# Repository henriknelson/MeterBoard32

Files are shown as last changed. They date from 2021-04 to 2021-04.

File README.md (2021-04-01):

# MeterBoard32
KiCad hardware project to integrate Texas Instruments TSS721-ADR M-Bus transceiver with Espressifs ESP32-WROOM module on a single PCB.

3D View:
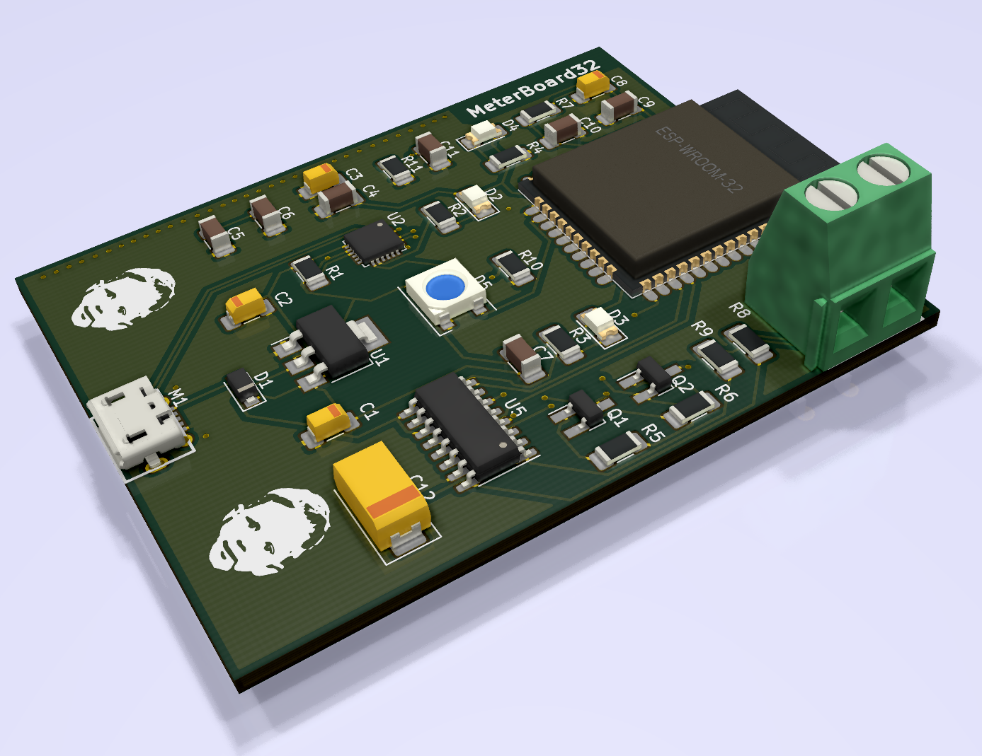
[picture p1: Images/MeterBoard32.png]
MeterBoard32 PCB 3D View


Schematic:
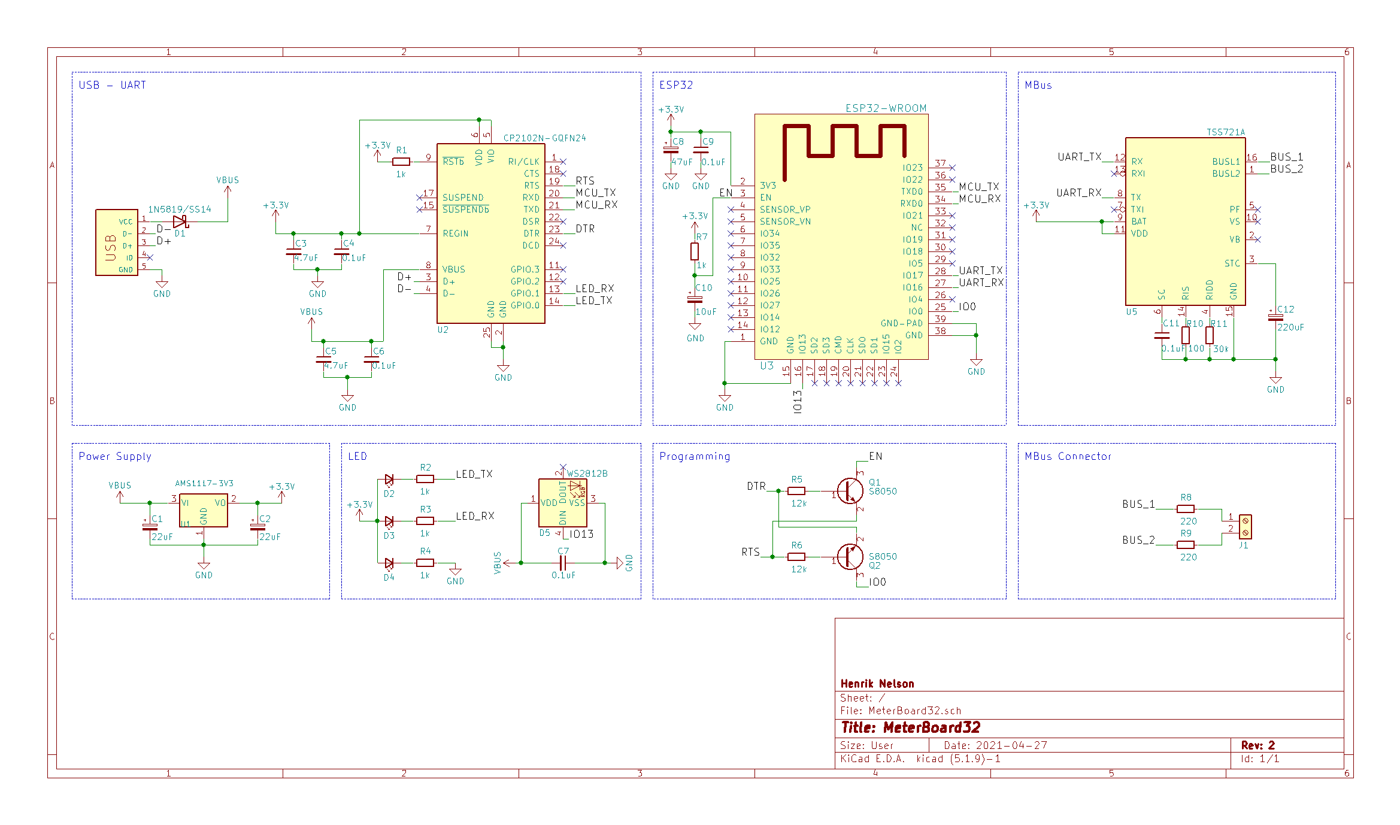
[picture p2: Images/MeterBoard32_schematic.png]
MeterBoard32 Schematic


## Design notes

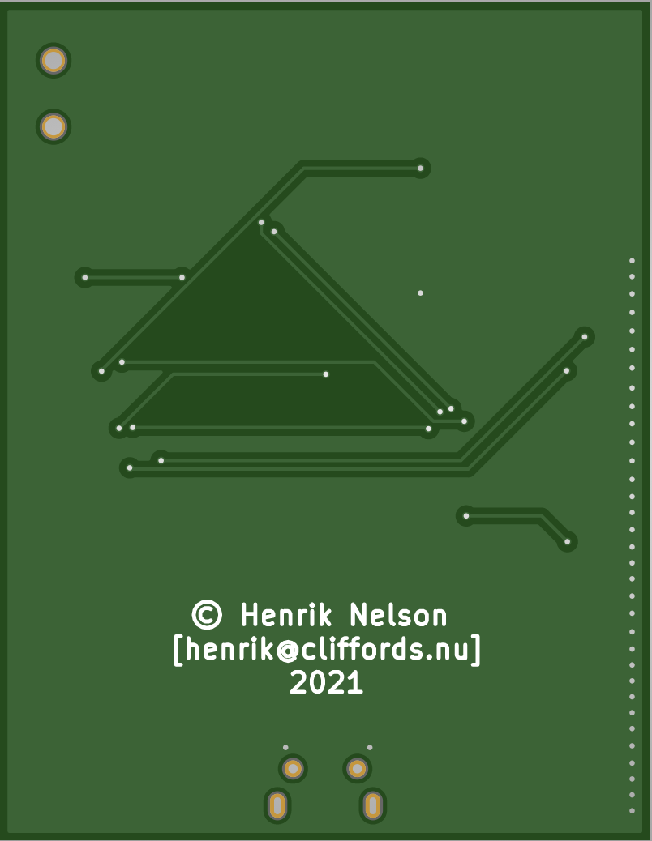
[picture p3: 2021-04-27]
Images/MeterBoard32_PCB_Back.png

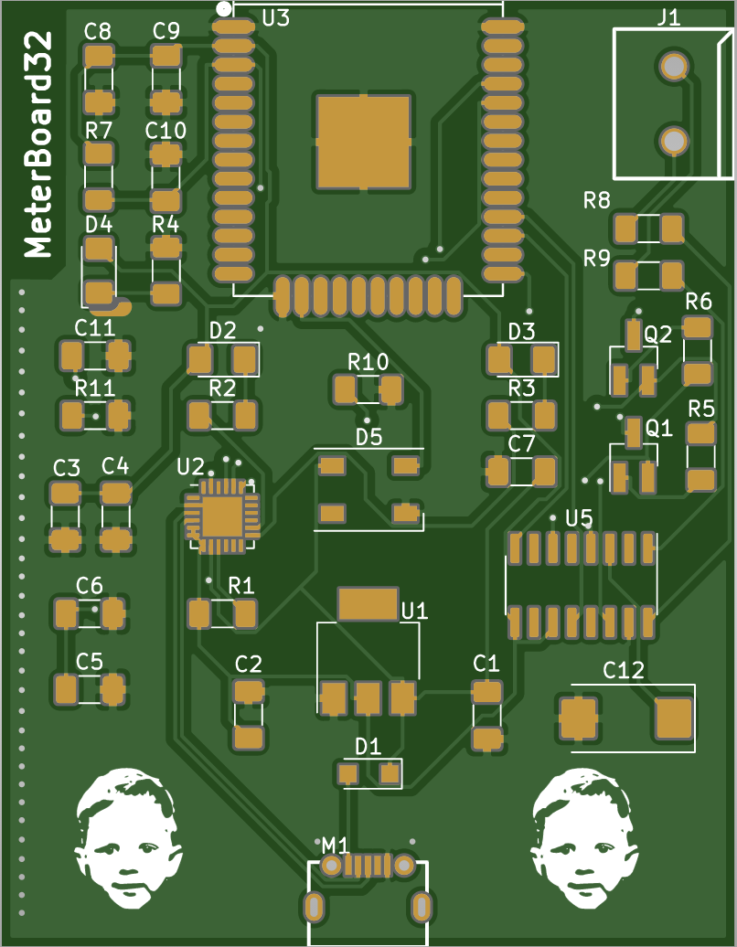
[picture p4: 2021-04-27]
Images/MeterBoard32_PCB_Front.png

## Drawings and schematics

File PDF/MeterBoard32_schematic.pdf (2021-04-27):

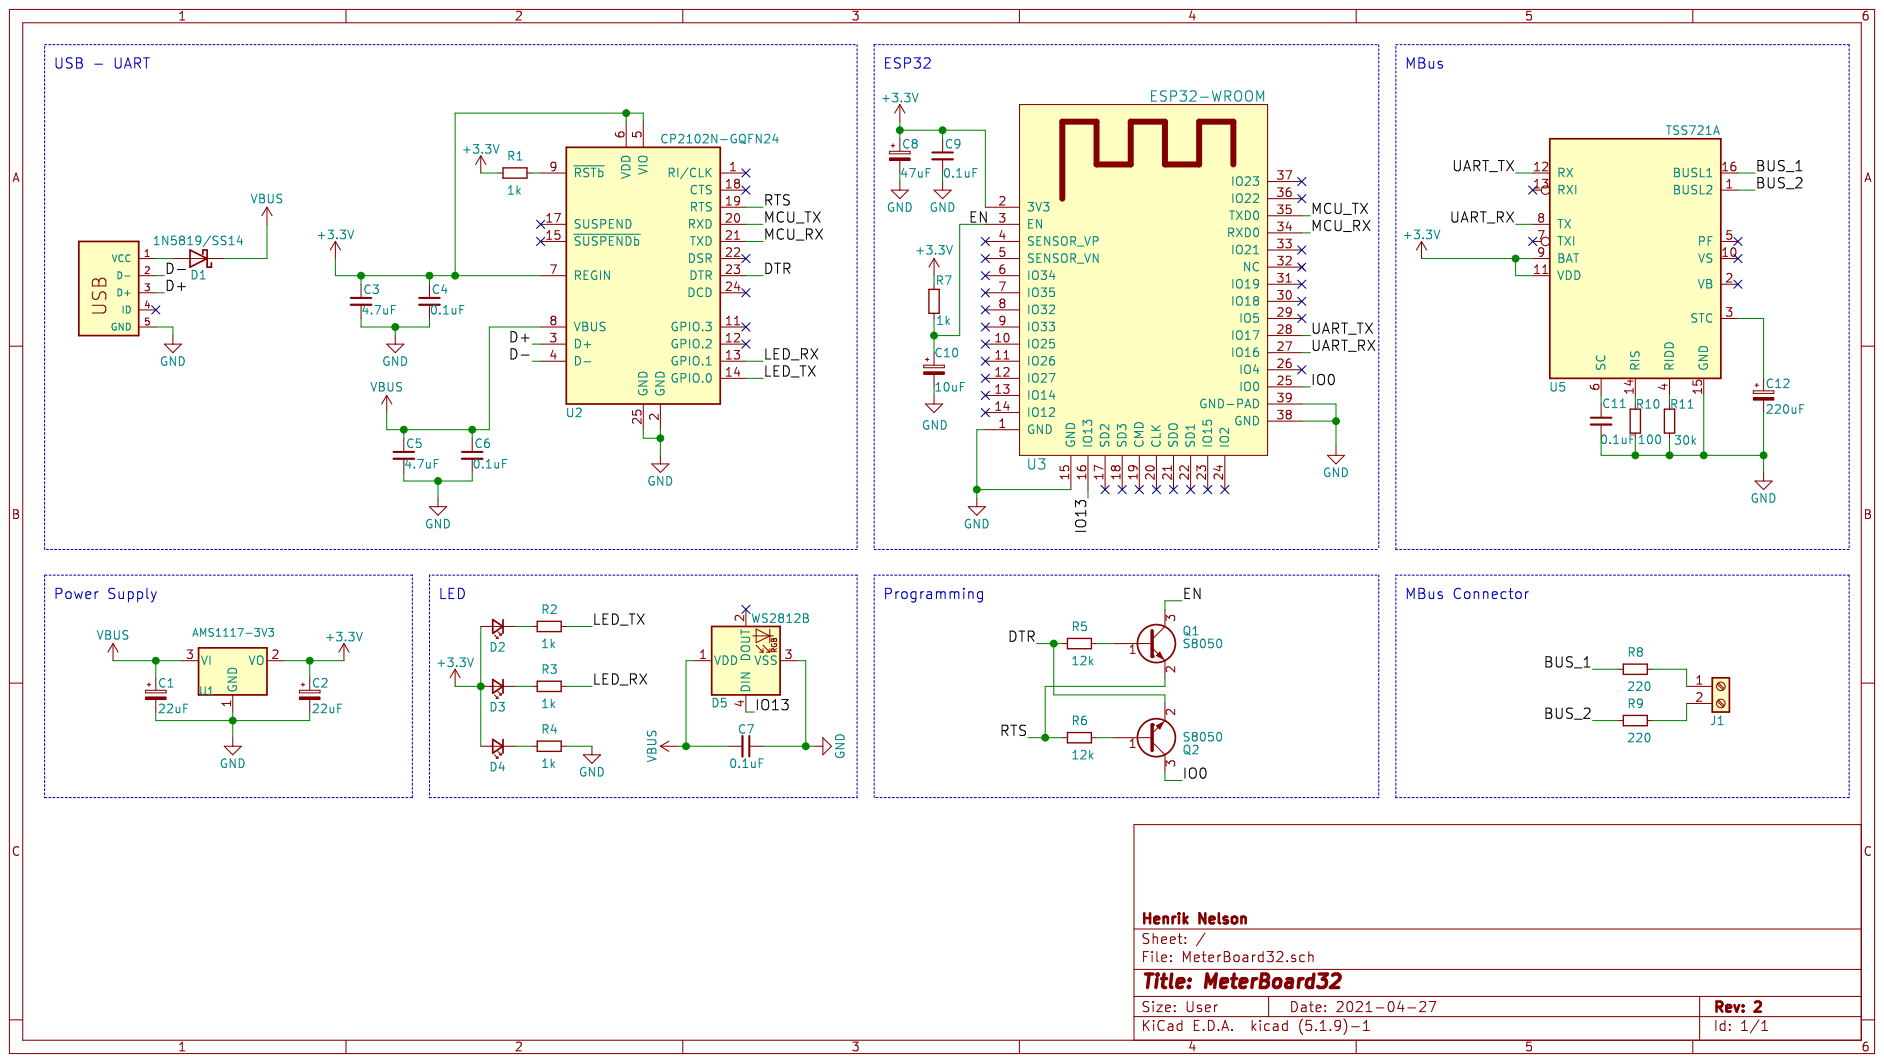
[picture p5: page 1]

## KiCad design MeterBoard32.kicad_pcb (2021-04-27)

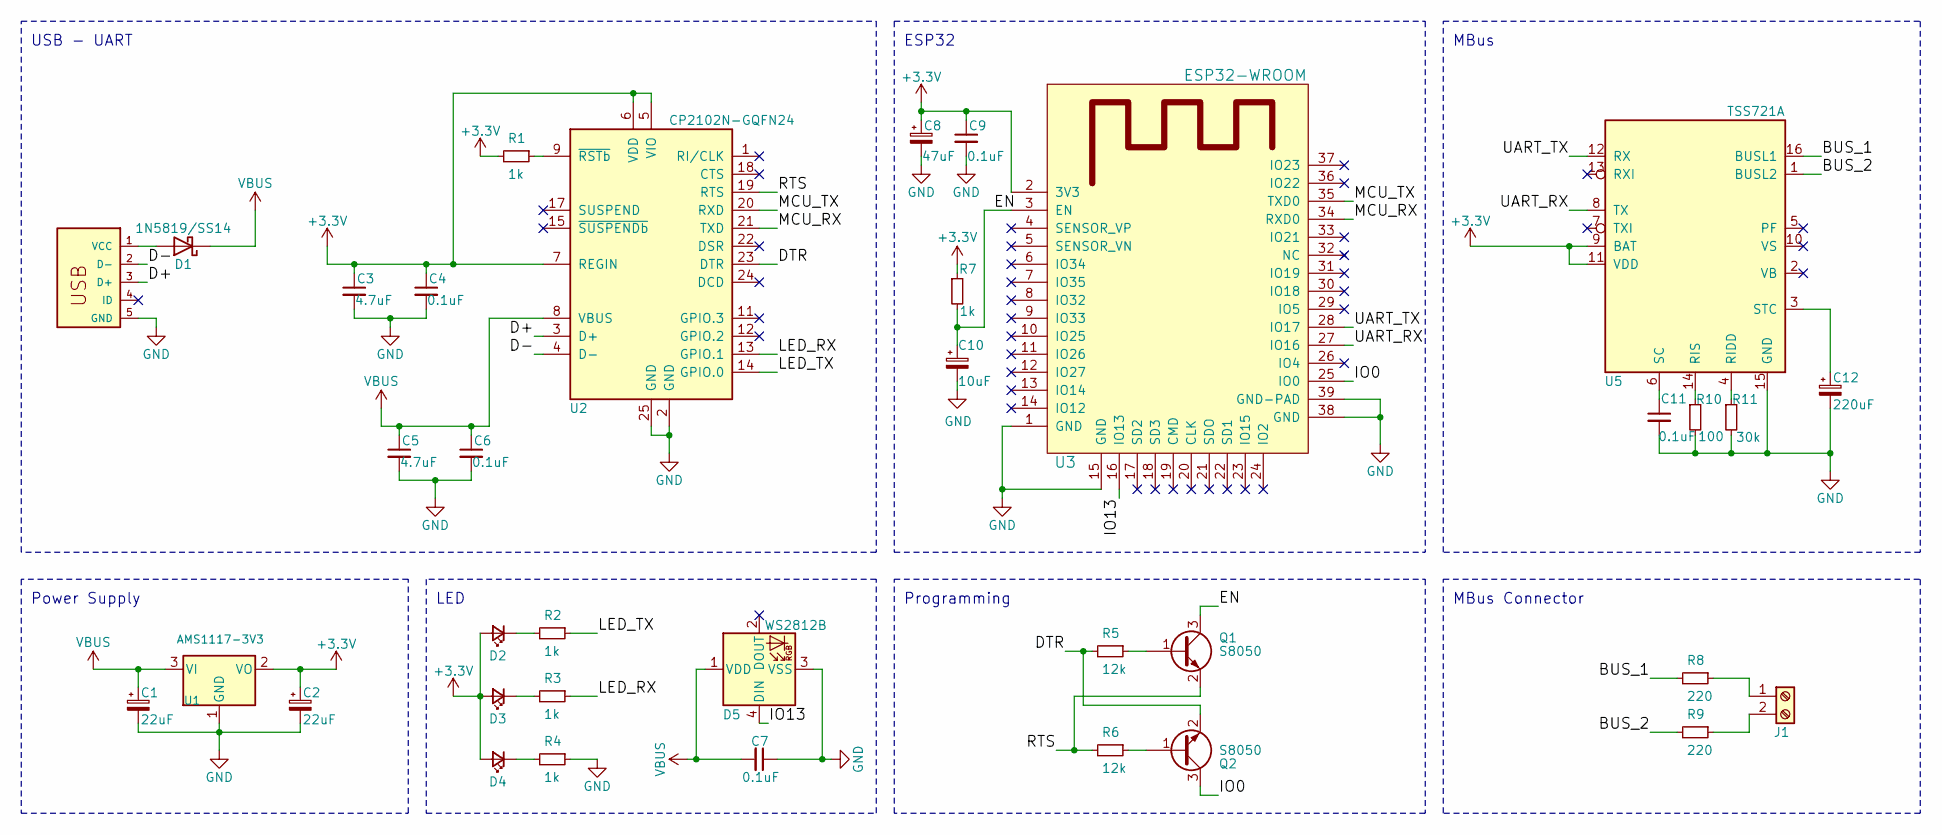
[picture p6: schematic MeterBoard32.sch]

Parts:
C1, C2: 22uF; C_1206_3216Metric_Pad1.33x1.80mm_HandSolder
C3, C5: 4.7uF; C_1206_3216Metric_Pad1.33x1.80mm_HandSolder
C4, C6, C7, C9, C11: 0.1uF; C_1206_3216Metric_Pad1.33x1.80mm_HandSolder
C8: 47uF; C_1206_3216Metric_Pad1.33x1.80mm_HandSolder
C10: 10uF; C_1206_3216Metric_Pad1.33x1.80mm_HandSolder
C12: 220uF; CP_EIA-7343-31_Kemet-D_Pad2.25x2.55mm_HandSolder
D1: 1N5819/SS14; D_SOD-123F
D2, D3, D4: LED_Small; LED_1206_3216Metric_Pad1.42x1.75mm_HandSolder
D5: WS2812B; LED_WS2812B_PLCC4_5.0x5.0mm_P3.2mm
J1: Screw_Terminal_01x02; TERMINAL_BLOCK_WJ126V_5_0_2P
M1: MICRO_USB_18_TH
Q1, Q2: S8050; SOT-23_Handsoldering
R1, R2, R3, R4, R7: 1k; R_1206_3216Metric_Pad1.30x1.75mm_HandSolder
R5, R6: 12k; R_1206_3216Metric_Pad1.30x1.75mm_HandSolder
R8, R9: 220; R_1206_3216Metric_Pad1.30x1.75mm_HandSolder
R10: 100; R_1206_3216Metric_Pad1.30x1.75mm_HandSolder
R11: 30k; R_1206_3216Metric_Pad1.30x1.75mm_HandSolder
U1: AMS1117-3V3; SOT-223
U2: CP2102N-GQFN24; QFN-24-1EP_4x4mm_P0.5mm_EP2.6x2.6mm
U3: ESP32-WROOM
U5: TSS721A; SOIC-16_3.9x9.9mm_P1.27mm

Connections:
+3V3: C2.1, C3.1, C4.1, C8.1, C9.1, D2.2 (A), D3.2 (A), D4.2 (A), R1.2, R7.1, U1.2 (VO), U2.5 (VIO), U2.6 (VDD), U2.7 (REGIN), U3.2 (3V3), U5.9 (BAT), U5.11 (VDD)
/BUS_1: R8.2, U5.16 (BUSL1)
/BUS_2: R9.2, U5.1 (BUSL2)
/D+: M1.3 (D+), U2.3 (D+)
/D-: M1.2 (D-), U2.4 (D-)
/DTR: Q2.2 (E), R5.2, U2.23 (DTR)
/EN: C10.1, Q1.3 (C), R7.2, U3.3 (EN)
/IO0: Q2.3 (C), U3.25 (IO0)
/IO13: D5.4 (DIN), U3.16 (IO13)
/LED_RX: R3.1, U2.13 (GPIO.1)
/LED_TX: R2.1, U2.14 (GPIO.0)
/MCU_RX: U2.21 (TXD), U3.34 (RXD0)
/MCU_TX: U2.20 (RXD), U3.35 (TXD0)
/RTS: Q1.2 (E), R6.2, U2.19 (RTS)
/UART_RX: U3.27 (IO16), U5.8 (TX)
/UART_TX: U3.28 (IO17), U5.12 (RX)
GND: C1.2, C2.2, C3.2, C4.2, C5.2, C6.2, C7.1, C8.2, C9.2, C10.2, C11.2, C12.2, D5.3 (VSS), M1.5 (GND), R4.1, R10.2, R11.2, U1.1 (GND), U2.2 (GND), U2.25 (GND), U3.1 (GND), U3.15 (GND), U3.38 (GND), U3.39 (GND-PAD), U5.15 (GND)
unnamed: C11.1, U5.6 (SC)
unnamed: C12.1, U5.3 (STC)
unnamed: D1.2 (A), M1.1 (VCC)
unnamed: D2.1 (K), R2.2
unnamed: D3.1 (K), R3.2
unnamed: D4.1 (K), R4.2
unnamed: J1.1, R8.1
unnamed: J1.2, R9.1
unnamed: Q1.1 (B), R5.1
unnamed: Q2.1 (B), R6.1
unnamed: R1.1, U2.9 (~RSTb)
unnamed: R10.1, U5.14 (RIS)
unnamed: R11.1, U5.4 (RIDD)
VBUS: C1.1, C5.1, C6.1, C7.2, D1.1 (K), D5.1 (VDD), U1.3 (VI), U2.8 (VBUS)

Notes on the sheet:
USB - UART
Power Supply
LED
ESP32
Programming
MBus
MBus Connector

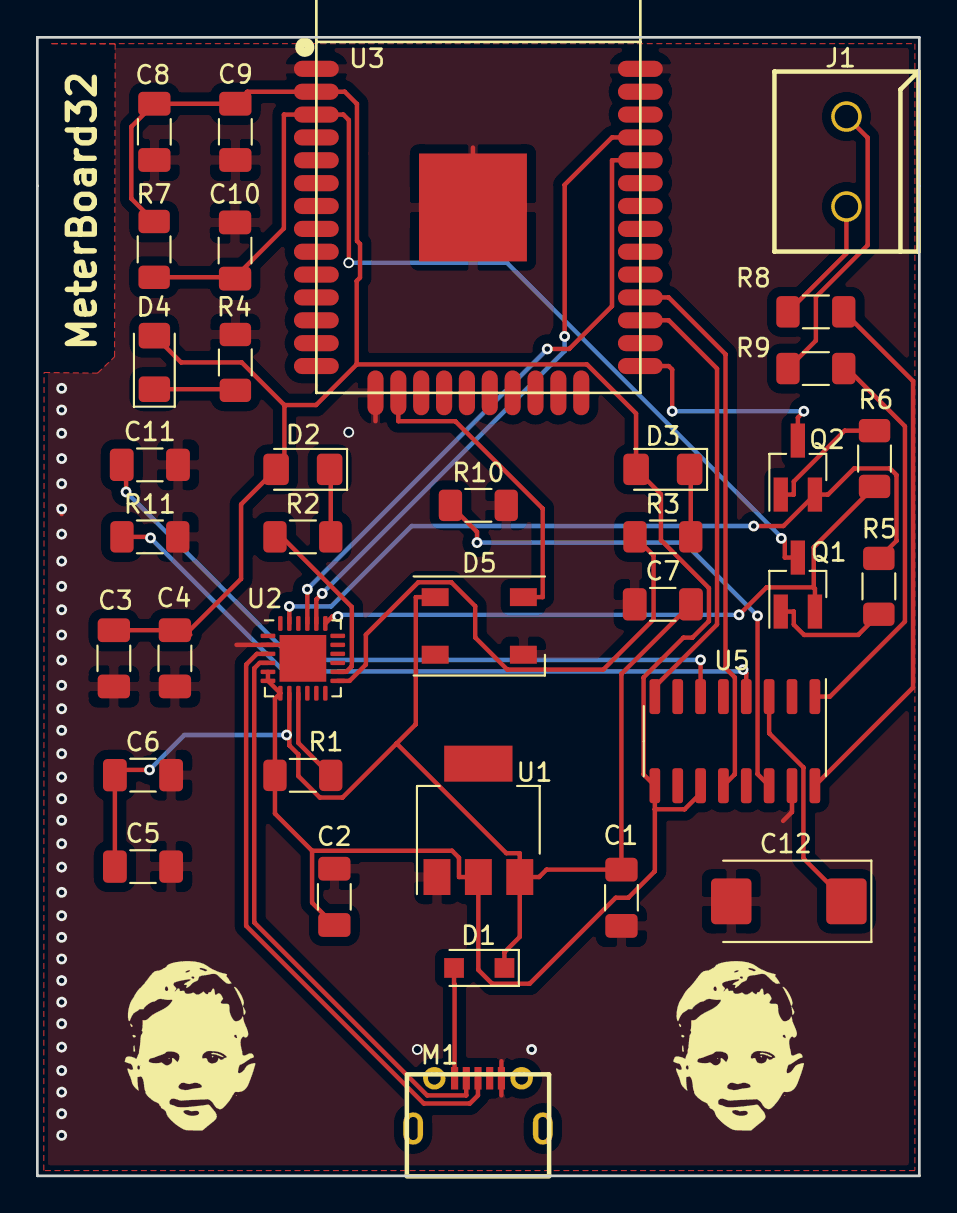
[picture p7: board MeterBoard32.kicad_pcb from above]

Board: 2 copper layers, 49.0 x 63.3 mm, 38 parts (0 on the bottom side), 31 nets.

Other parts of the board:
G1, G1#2: LOGO; Harry_3

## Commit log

2018-03-16 Added project files
    [MeterBoard32.dsn, MeterBoard32.kicad_pcb, MeterBoard32.sch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]
2018-03-17 Added schematics for TSS721A
    [MeterBoard32.sch]
2018-03-22 Added KiCad project files
    [MeterBoard32.kicad_pcb, MeterBoard32.sch]
2018-03-22 Changed name from MbusBoard32 to MeterBoard32
    [MeterBoard32.kicad_pcb, MeterBoard32.sch]
2018-03-22 Added Gerber files
    [MeterBoard32-B.Cu.gbr, MeterBoard32-B.Mask.gbr, MeterBoard32-B.SilkS.gbr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]
2018-03-22 Added Front/Back PCB / 3D images
2018-03-22 Added schematic PDF
2018-03-22 Added additional KiCad files
    [MeterBoard32.dsn]
2018-03-22 Added schematic PNG file
2018-03-22 Updated README with PCB 3D and schematic images
2021-04-26 Converted old KiCad 4 project file to KiCad 5
    [MeterBoard32-2021-04-16-13-24-26.sch]
2021-04-26 Small fix
    [MeterBoard32.kicad_pcb]
2021-04-26 Small fixes again..
    [MeterBoard32.kicad_pcb]
2021-04-26 Fixed 3D models
    [MeterBoard32.kicad_pcb, MeterBoard32.sch]
2021-04-27 Finished the conversion of MeterBoard32 from KiCad 4 to KiCad 5
    [MeterBoard32-2021-04-16-13-24-26.sch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]

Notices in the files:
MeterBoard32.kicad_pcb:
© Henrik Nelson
